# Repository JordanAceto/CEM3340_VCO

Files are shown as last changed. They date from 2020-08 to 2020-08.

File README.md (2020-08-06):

# CEM3340 based VCO PCB

## Features:
- Sine, Triangle, Sawtooth, and variable Pulse waves simultaneously available.
- All waveforms +/- 5vpp.
- Three 1 volt/octave inputs, linear FM, sync (choose hard or soft), and PWM modulation inputs.
- Onboard voltage regulators and reference voltage generators for stable tuning.
- Input voltage can be either +/- 12 volts DC, or +/- 15 volts DC.
- Designed to either plug into a separate carrier pcb with pots and jacks, or mount to a bracket and wire by hand. 

## A note about the pulse waveform:
 This design does not use the built in CEM3340 pulse generator. Instead, an typical opamp circuit is used for the Pulse wave output. This is to avoid the influence of PWM on the frequency of the oscillator, which has been reported to be a problem, especially with the AS3340 versions of the chip. The built in pulse generator is disabled by tying the output to ground through a resistor, and hardwiring a negative voltage into pin 5 which permanently sets the pulse width to zero percent.

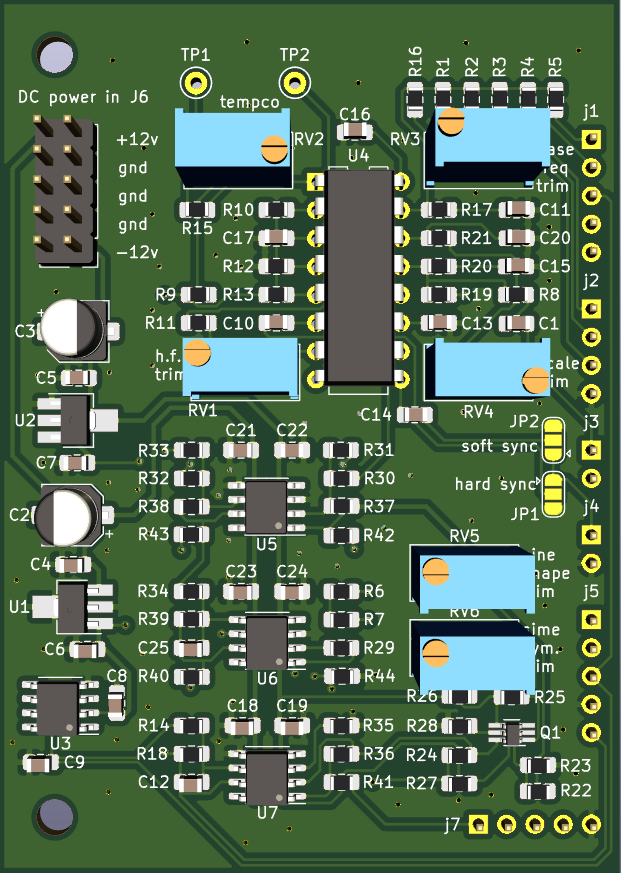
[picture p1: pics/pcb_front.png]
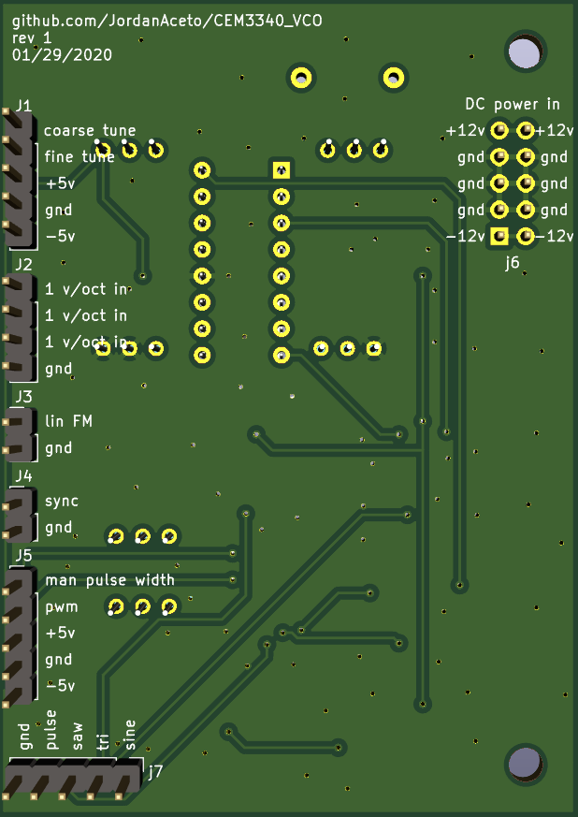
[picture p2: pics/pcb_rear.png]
   

## Status of the project:

Revision | breadboarded | schematic | pcb layout | built and tested | documentation
---------|--------------|-----------|------------|------------------|---------------
1        | &#9745;      | &#9745;   | &#9745;    | &#9745;          | &#9745; 

## Informal evaluation:

I've built three of these, and they work well and are fairly easy to build. The dual NPN in the sine shaper is a little small, but after doing a few of them I can solder them reliably without any grief.

Calibration is pretty straightforward and they tune up nicely and don't drift badly with changes in temperature. I have not done any rigorous testing, just by-ear, but I'm pretty picky about out of tune VCOs and these seem good to me so far.

Overall quite happy with this VCO.

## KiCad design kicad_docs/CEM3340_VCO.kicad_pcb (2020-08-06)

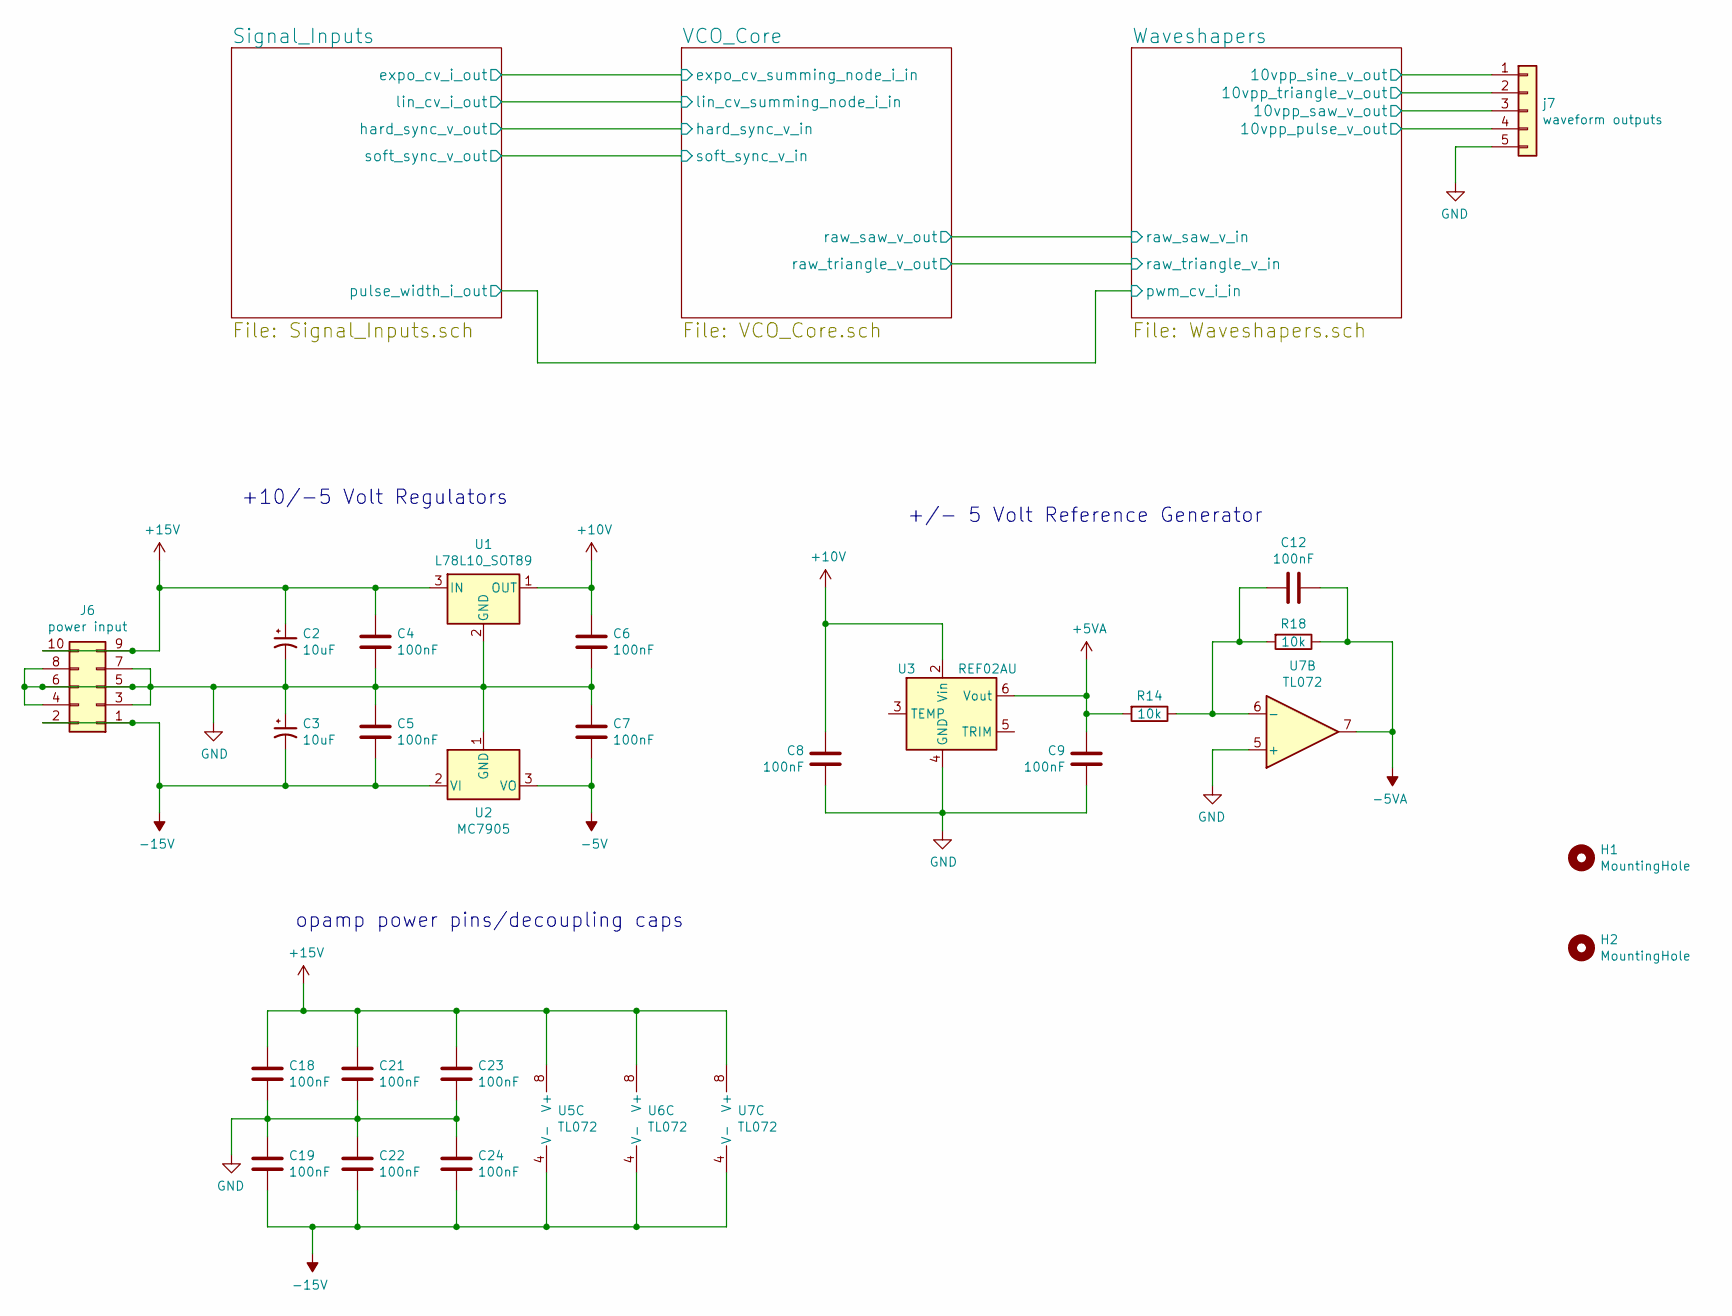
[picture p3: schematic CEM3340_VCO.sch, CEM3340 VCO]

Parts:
C2, C3: 10uF; CP_Elec_5x5.4
C4, C5, C6, C7, C8, C9, C12, C18, C19, C21, C22, C23, C24: 100nF; C_0805_2012Metric_Pad1.15x1.40mm_HandSolder
H1, H2: MountingHole; MountingHole_3.2mm_M3
J6: power input; PinHeader_2x05_P2.54mm_Vertical
R14, R18: 10k; R_0805_2012Metric_Pad1.15x1.40mm_HandSolder
U1: L78L10_SOT89; SOT-89-3_Handsoldering
U2: MC7905; SOT-89-3_Handsoldering
U3: REF02AU; SOIC-8_3.9x4.9mm_P1.27mm
U5, U6, U7: TL072; SOIC-8_3.9x4.9mm_P1.27mm
j7: waveform outputs; PinHeader_1x05_P2.54mm_Vertical

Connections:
+5VA: C9.2, R14.2, U3.6 (Vout); also elsewhere on the board
+10V: C6.2, C8.2, U1.1 (OUT), U3.2 (Vin); also elsewhere on the board
+15V: C2.1, C4.1, C18.1, C21.1, C23.1, J6.9, J6.10, U1.3 (IN), U5.8 (V+), U6.8 (V+), U7.8 (V+); also elsewhere on the board
-5V: C7.1, U2.3 (VO); also elsewhere on the board
-5VA: C12.1, R18.1, U7.7; also elsewhere on the board
-15V: C3.2, C5.2, C19.2, C22.2, C24.2, J6.1, J6.2, U2.2 (VI), U5.4 (V-), U6.4 (V-), U7.4 (V-); also elsewhere on the board
/Waveshapers/10vpp_pulse_v_out: j7.4; also elsewhere on the board
/Waveshapers/10vpp_saw_v_out: j7.3; also elsewhere on the board
/Waveshapers/10vpp_sine_v_out: j7.1; also elsewhere on the board
/Waveshapers/10vpp_triangle_v_out: j7.2; also elsewhere on the board
GND: C2.2, C3.1, C4.2, C5.1, C6.1, C7.2, C8.1, C9.1, C18.2, C19.1, C21.2, C22.1, C23.2, C24.1, J6.3, J6.4, J6.5, J6.6, J6.7, J6.8, U1.2 (GND), U2.1 (GND), U3.4 (GND), U7.5 (+), j7.5; also elsewhere on the board
unnamed: C12.2, R14.1, R18.2, U7.6 (-)

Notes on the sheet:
+/- 5 Volt Reference Generator
+10/-5 Volt Regulators
opamp power pins/decoupling caps

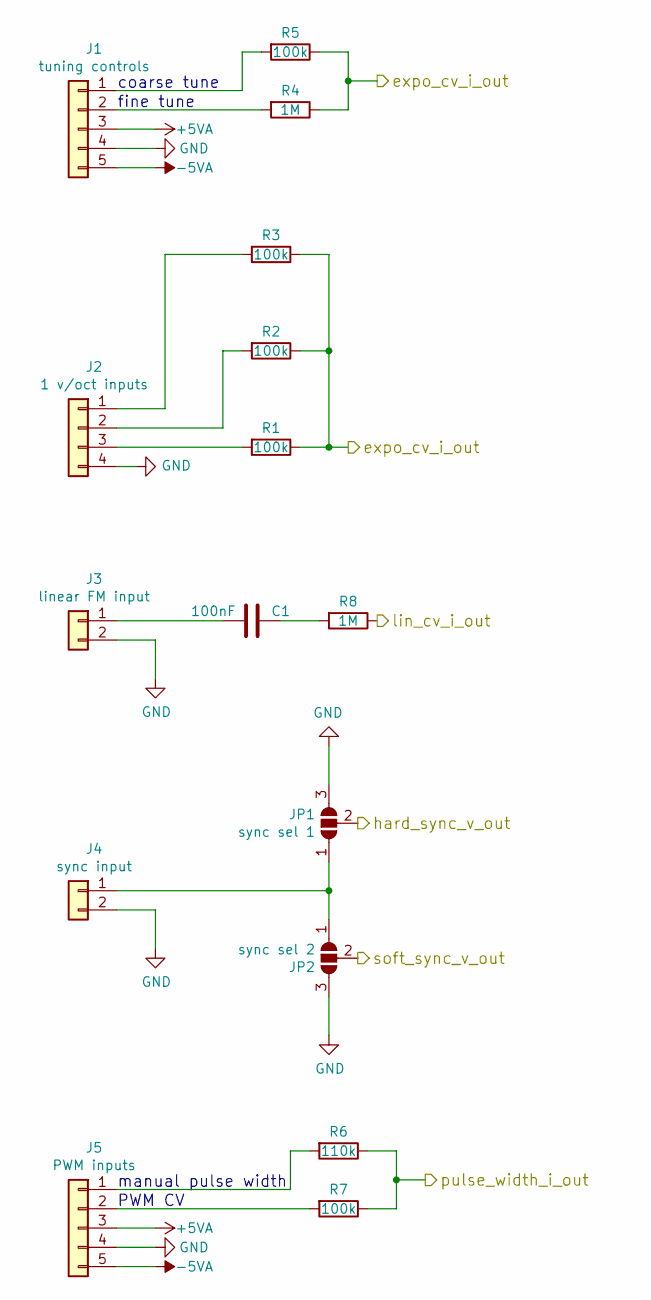
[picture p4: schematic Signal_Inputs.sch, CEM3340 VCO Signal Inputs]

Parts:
C1: 100nF; C_0805_2012Metric_Pad1.15x1.40mm_HandSolder
J1: tuning controls; PinHeader_1x05_P2.54mm_Vertical
J2: 1 v/oct inputs; PinHeader_1x04_P2.54mm_Vertical
J3: linear FM input; PinHeader_1x02_P2.54mm_Vertical
J4: sync input; PinHeader_1x02_P2.54mm_Vertical
J5: PWM inputs; PinHeader_1x05_P2.54mm_Vertical
JP1: sync sel 1; SolderJumper-3_P1.3mm_Open_RoundedPad1.0x1.5mm
JP2: sync sel 2; SolderJumper-3_P1.3mm_Open_RoundedPad1.0x1.5mm
R1, R2, R3, R5, R7: 100k; R_0805_2012Metric_Pad1.15x1.40mm_HandSolder
R4, R8: 1M; R_0805_2012Metric_Pad1.15x1.40mm_HandSolder
R6: 110k; R_0805_2012Metric_Pad1.15x1.40mm_HandSolder

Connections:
+5VA: J1.3, J5.3; also elsewhere on the board
-5VA: J1.5, J5.5; also elsewhere on the board
/Signal_Inputs/expo_cv_i_out: R1.1, R2.1, R3.1, R4.1, R5.1; also elsewhere on the board
/Signal_Inputs/lin_cv_i_out: R8.1; also elsewhere on the board
/Signal_Inputs/pulse_width_i_out: R6.1, R7.1
/VCO_Core/hard_sync_v_in: JP1.2 (C); also elsewhere on the board
/VCO_Core/soft_sync_v_in: JP2.2 (C); also elsewhere on the board
GND: J1.4, J2.4, J3.2, J4.2, J5.4, JP1.3 (B), JP2.3 (B); also elsewhere on the board
unnamed: C1.1, R8.2
unnamed: C1.2, J3.1
unnamed: J1.1, R5.2
unnamed: J1.2, R4.2
unnamed: J2.1, R3.2
unnamed: J2.2, R2.2
unnamed: J2.3, R1.2
unnamed: J4.1, JP1.1 (A), JP2.1 (A)
unnamed: J5.1, R6.2
unnamed: J5.2, R7.2

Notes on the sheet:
manual pulse width
PWM CV
fine tune
coarse tune

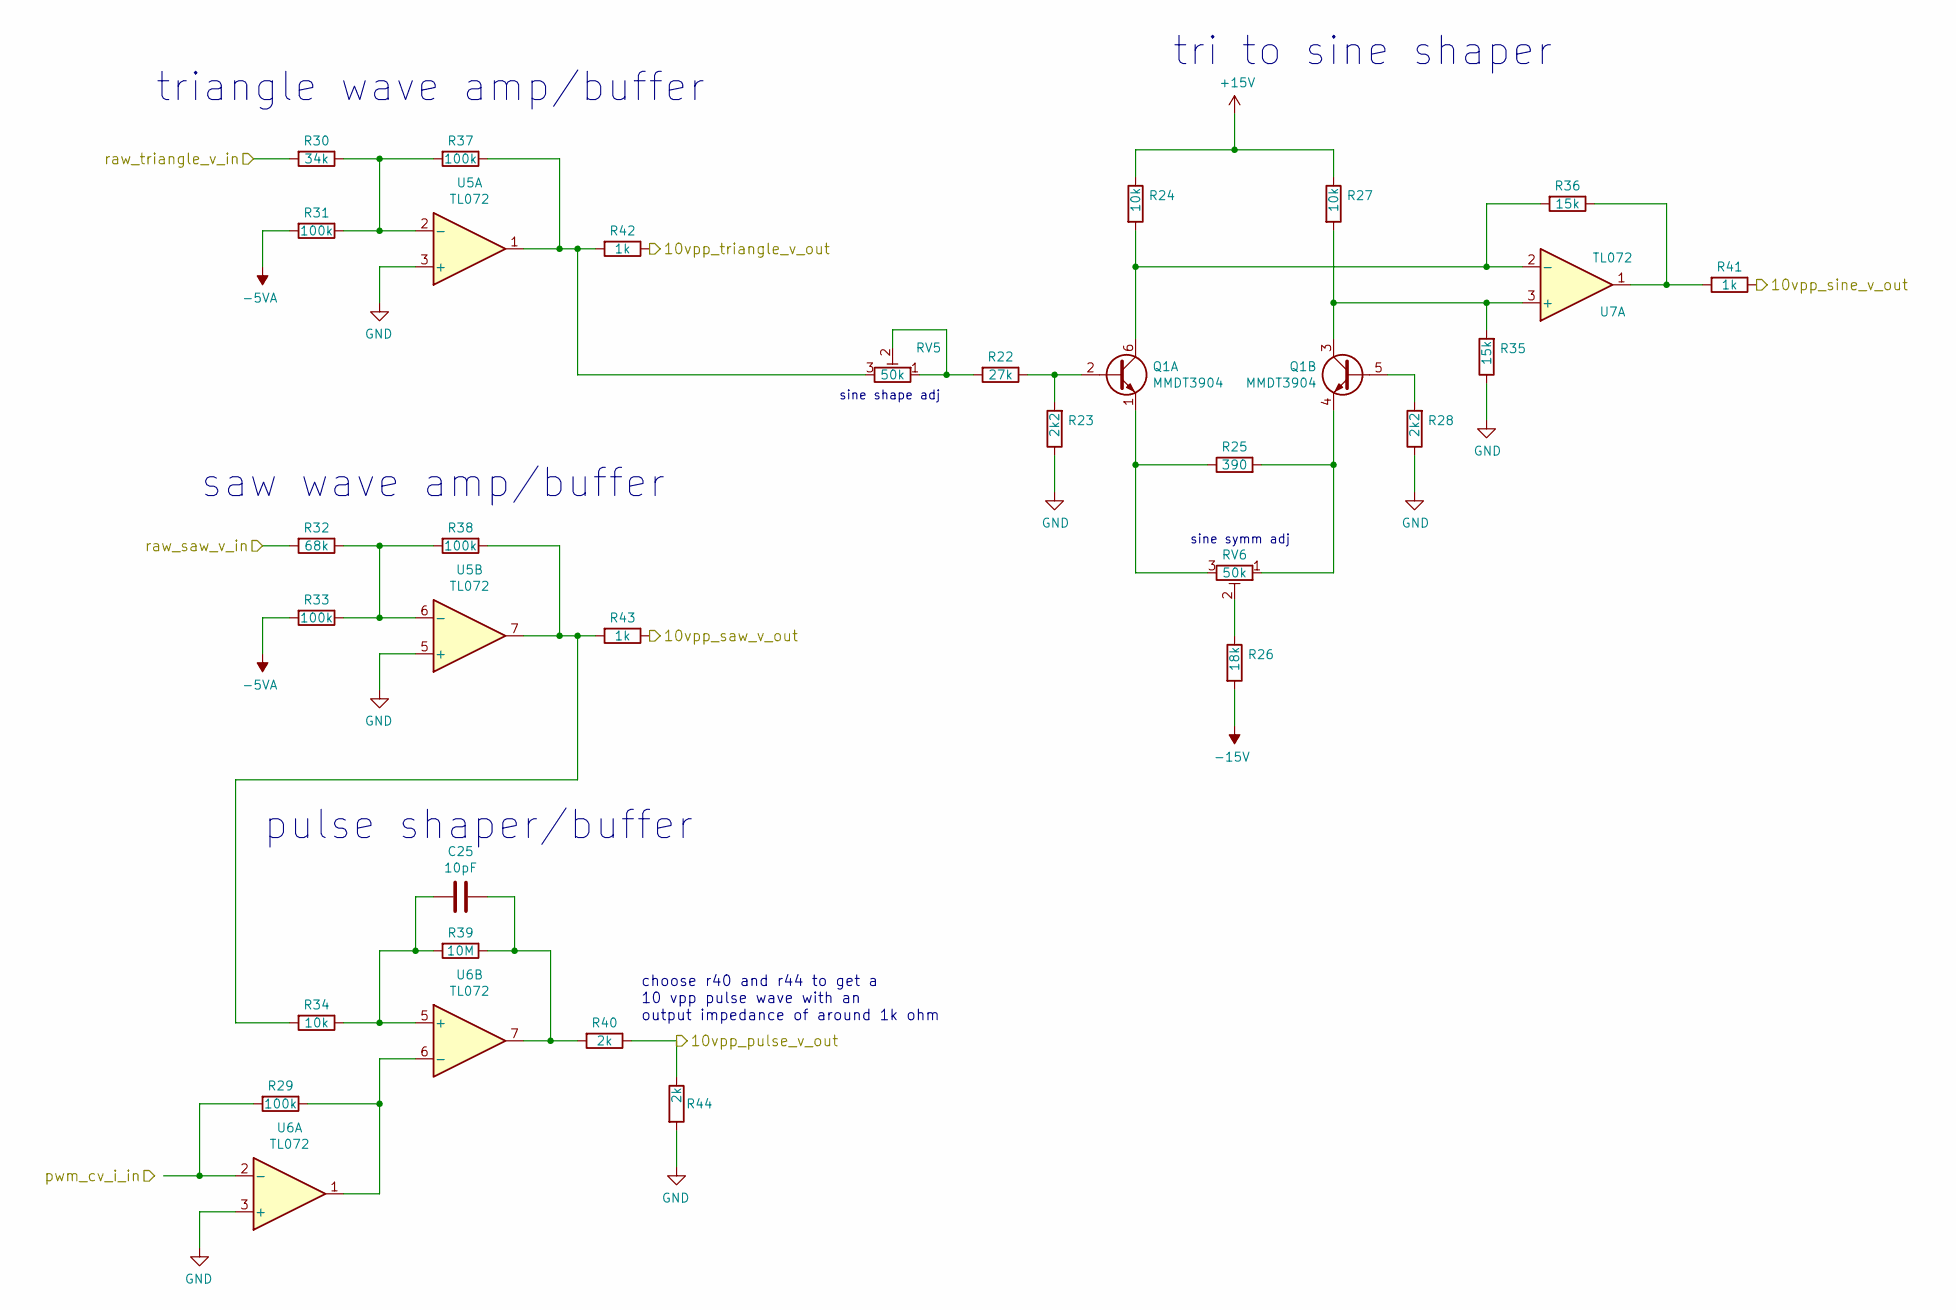
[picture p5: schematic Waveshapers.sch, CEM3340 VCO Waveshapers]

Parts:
C25: 10pF; C_0805_2012Metric_Pad1.15x1.40mm_HandSolder
Q1: MMDT3904; SOT-363_SC-70-6_Handsoldering
R22: 27k; R_0805_2012Metric_Pad1.15x1.40mm_HandSolder
R23, R28: 2k2; R_0805_2012Metric_Pad1.15x1.40mm_HandSolder
R24, R27, R34: 10k; R_0805_2012Metric_Pad1.15x1.40mm_HandSolder
R25: 390; R_0805_2012Metric_Pad1.15x1.40mm_HandSolder
R26: 18k; R_0805_2012Metric_Pad1.15x1.40mm_HandSolder
R29, R31, R33, R37, R38: 100k; R_0805_2012Metric_Pad1.15x1.40mm_HandSolder
R30: 34k; R_0805_2012Metric_Pad1.15x1.40mm_HandSolder
R32: 68k; R_0805_2012Metric_Pad1.15x1.40mm_HandSolder
R35, R36: 15k; R_0805_2012Metric_Pad1.15x1.40mm_HandSolder
R39: 10M; R_0805_2012Metric_Pad1.15x1.40mm_HandSolder
R40, R44: 2k; R_0805_2012Metric_Pad1.15x1.40mm_HandSolder
R41, R42, R43: 1k; R_0805_2012Metric_Pad1.15x1.40mm_HandSolder
RV5, RV6: 50k; Potentiometer_Bourns_3296W_Vertical
U5, U6, U7: TL072; SOIC-8_3.9x4.9mm_P1.27mm

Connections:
+15V: R24.1, R27.1; also elsewhere on the board
-5VA: R31.2, R33.2; also elsewhere on the board
-15V: R26.2; also elsewhere on the board
/Waveshapers/10vpp_pulse_v_out: R40.1, R44.1; also elsewhere on the board
/Waveshapers/10vpp_saw_v_out: R43.1; also elsewhere on the board
/Waveshapers/10vpp_sine_v_out: R41.1; also elsewhere on the board
/Waveshapers/10vpp_triangle_v_out: R42.1; also elsewhere on the board
/Waveshapers/raw_saw_v_in: R32.2; also elsewhere on the board
/Waveshapers/raw_triangle_v_in: R30.2; also elsewhere on the board
GND: R23.1, R28.1, R35.1, R44.2, U5.3 (+), U5.5 (+), U6.3 (+); also elsewhere on the board
unnamed: C25.1, R39.1, R40.2, U6.7
unnamed: C25.2, R34.1, R39.2, U6.5 (+)
unnamed: Q1.1 (E1), R25.1, RV6.3
unnamed: Q1.2 (B1), R22.1, R23.2
unnamed: Q1.3 (C2), R27.2, R35.2, U7.3 (+)
unnamed: Q1.4 (E2), R25.2, RV6.1
unnamed: Q1.5 (B2), R28.2
unnamed: Q1.6 (C1), R24.2, R36.2, U7.2 (-)
unnamed: R22.2, RV5.1, RV5.2
unnamed: R26.1, RV6.2
unnamed: R29.1, U6.1, U6.6 (-)
unnamed: R29.2, U6.2 (-)
unnamed: R30.1, R31.1, R37.2, U5.2 (-)
unnamed: R32.1, R33.1, R38.2, U5.6 (-)
unnamed: R34.2, R38.1, R43.2, U5.7
unnamed: R36.1, R41.2, U7.1
unnamed: R37.1, R42.2, RV5.3, U5.1

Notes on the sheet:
sine shape adj
sine symm adj
tri to sine shaper
triangle wave amp/buffer
saw wave amp/buffer
pulse shaper/buffer
choose r40 and r44 to get a 10 vpp pulse wave with an output impedance of around 1k ohm

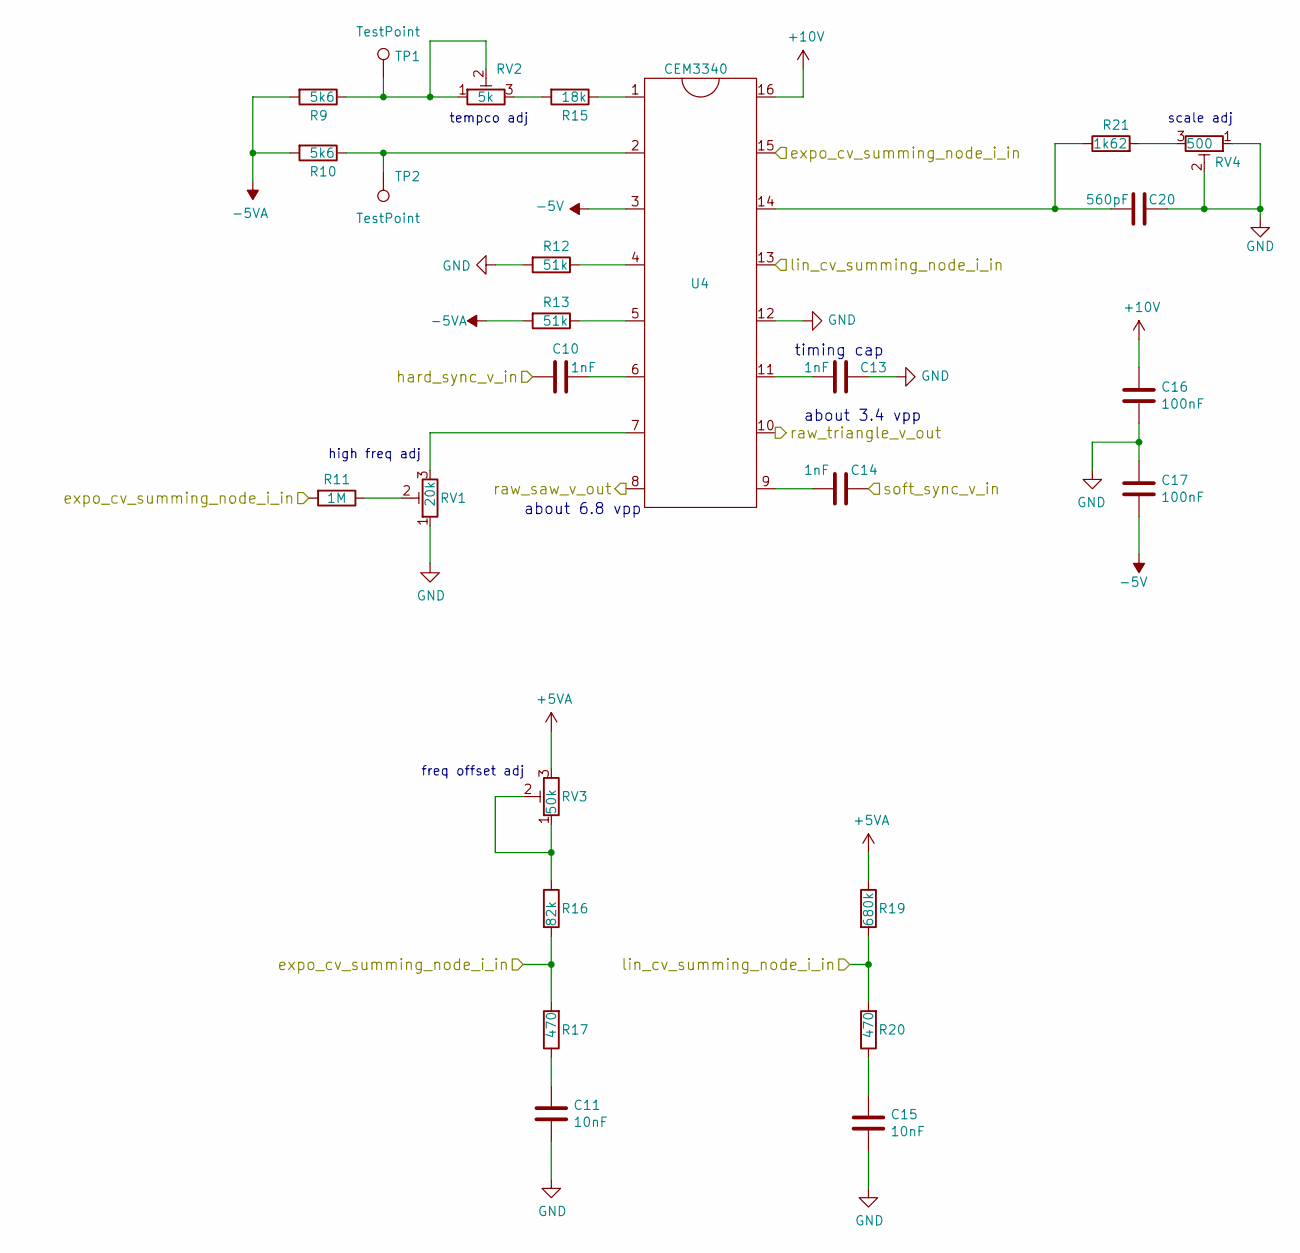
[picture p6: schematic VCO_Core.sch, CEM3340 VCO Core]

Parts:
C10, C13, C14: 1nF; C_0805_2012Metric_Pad1.15x1.40mm_HandSolder
C11, C15: 10nF; C_0805_2012Metric_Pad1.15x1.40mm_HandSolder
C16, C17: 100nF; C_0805_2012Metric_Pad1.15x1.40mm_HandSolder
C20: 560pF; C_0805_2012Metric_Pad1.15x1.40mm_HandSolder
R9, R10: 5k6; R_0805_2012Metric_Pad1.15x1.40mm_HandSolder
R11: 1M; R_0805_2012Metric_Pad1.15x1.40mm_HandSolder
R12, R13: 51k; R_0805_2012Metric_Pad1.15x1.40mm_HandSolder
R15: 18k; R_0805_2012Metric_Pad1.15x1.40mm_HandSolder
R16: 82k; R_0805_2012Metric_Pad1.15x1.40mm_HandSolder
R17, R20: 470; R_0805_2012Metric_Pad1.15x1.40mm_HandSolder
R19: 680k; R_0805_2012Metric_Pad1.15x1.40mm_HandSolder
R21: 1k62; R_0805_2012Metric_Pad1.15x1.40mm_HandSolder
RV1: 20k; Potentiometer_Bourns_3296W_Vertical
RV2: 5k; Potentiometer_Bourns_3296W_Vertical
RV3: 50k; Potentiometer_Bourns_3296W_Vertical
RV4: 500; Potentiometer_Bourns_3296W_Vertical
TP1, TP2: TestPoint; TestPoint_Keystone_5000-5004_Miniature
U4: CEM3340; DIP-16_W7.62mm

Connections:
+5VA: R19.1, RV3.3; also elsewhere on the board
+10V: C16.1, U4.16; also elsewhere on the board
-5V: C17.2, U4.3; also elsewhere on the board
-5VA: R9.2, R10.2, R13.2; also elsewhere on the board
/Signal_Inputs/expo_cv_i_out: R11.2, R16.2, R17.2, U4.15; also elsewhere on the board
/Signal_Inputs/lin_cv_i_out: R19.2, R20.2, U4.13; also elsewhere on the board
/VCO_Core/hard_sync_v_in: C10.2; also elsewhere on the board
/VCO_Core/soft_sync_v_in: C14.1; also elsewhere on the board
/Waveshapers/raw_saw_v_in: U4.8; also elsewhere on the board
/Waveshapers/raw_triangle_v_in: U4.10; also elsewhere on the board
GND: C11.2, C13.1, C15.2, C16.2, C17.1, C20.2, R12.2, RV1.1, RV4.1, RV4.2, U4.12; also elsewhere on the board
unnamed: C10.1, U4.6
unnamed: C11.1, R17.1
unnamed: C13.2, U4.11
unnamed: C14.2, U4.9
unnamed: C15.1, R20.1
unnamed: C20.1, R21.1, U4.14
unnamed: R9.1, RV2.1, RV2.2, TP1.1
unnamed: R10.1, TP2.1, U4.2
unnamed: R11.1, RV1.2
unnamed: R12.1, U4.4
unnamed: R13.1, U4.5
unnamed: R15.1, U4.1
unnamed: R15.2, RV2.3
unnamed: R16.1, RV3.1, RV3.2
unnamed: R21.2, RV4.3
unnamed: RV1.3, U4.7

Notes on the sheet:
tempco adj
scale adj
freq offset adj
high freq adj
timing cap
about 3.4 vpp
about 6.8 vpp

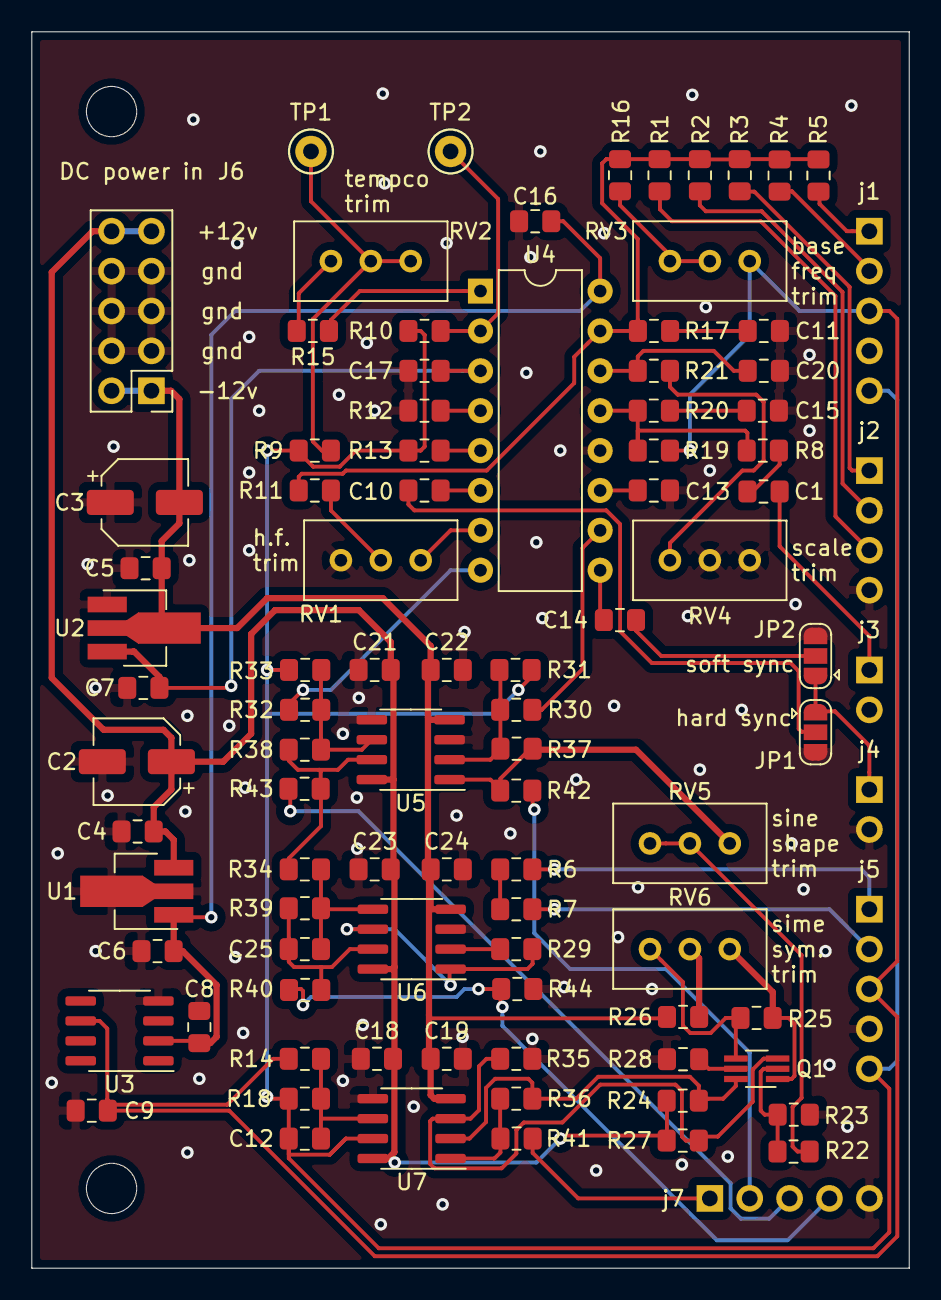
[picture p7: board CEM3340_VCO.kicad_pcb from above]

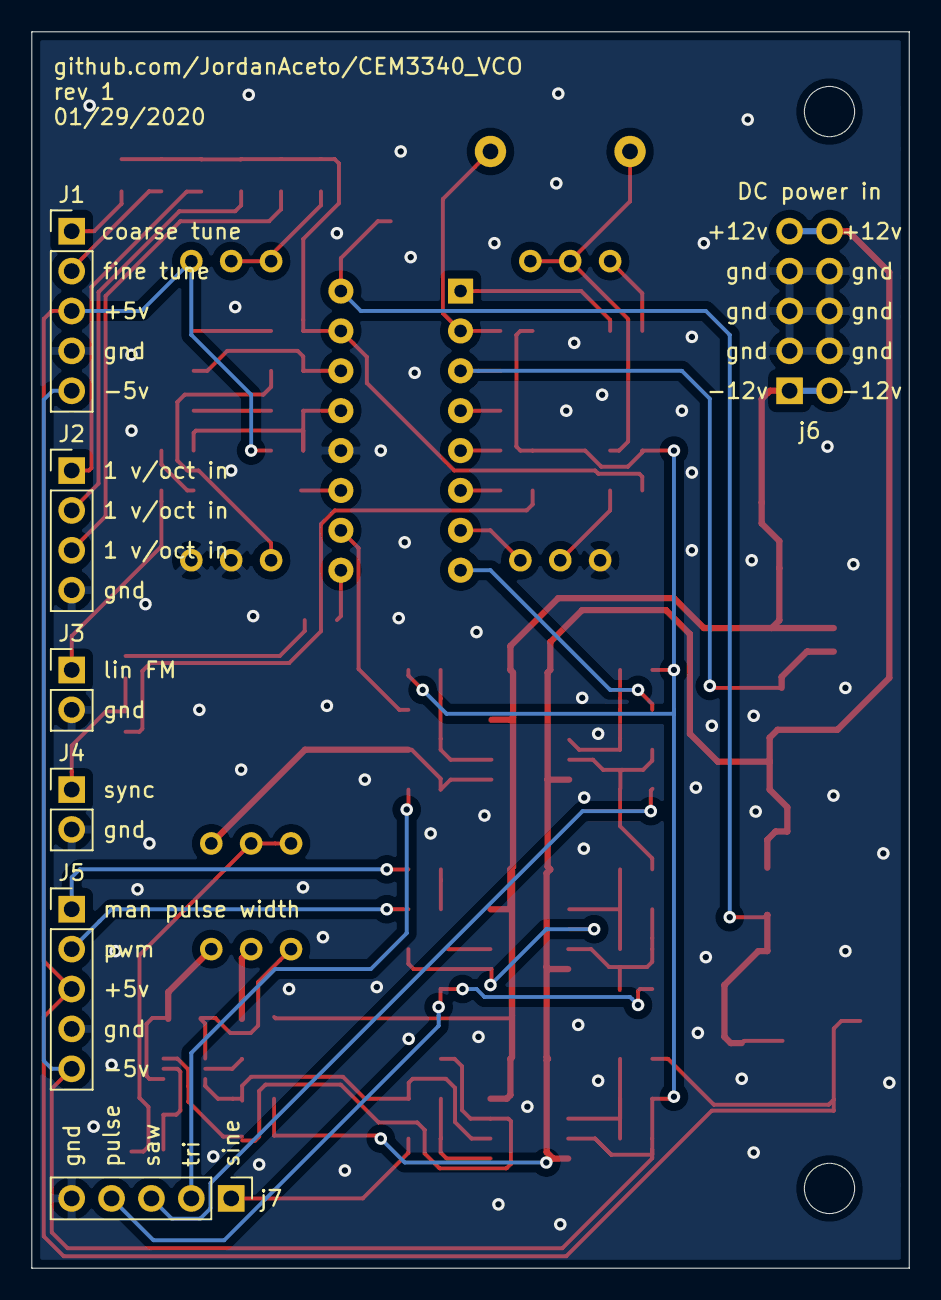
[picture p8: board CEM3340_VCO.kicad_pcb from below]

Board: 2 copper layers, 55.9 x 78.7 mm, 96 parts (6 on the bottom side), 62 nets.

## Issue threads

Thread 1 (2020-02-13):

Transistor pair is too small.

JordanAceto, 2020-02-13:
The MMDT3904 matched transistor pair Q1 package is too small to easily/reliably hand solder. This part should be replaced by either a larger NPN pair, or 2 discrete NPN transistors in reasonably sized packages.

A cheap matched pair that comes in a (fairly) easily hand soldered package can be found here: https://www.mouser.com/ProductDetail/771-BCM847DS115

JordanAceto, 2020-08-06:
It's really not too bad after doing a few of them. If a new pcb rev happens then sure, put in a bigger package, but don't do it just for this.

Closed 2020-08-06.

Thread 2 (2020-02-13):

Sine adjustment should not rely on the raw power input voltage

JordanAceto, 2020-02-13:
The sine wave shaper transistor pair Q1 is across the raw +/- DC power supply input rails. For sine calibration that does not depend on the input voltage, this should be changed so that it is across the derived +10/-5 volt sub-rails. Some adjustment of component values may be needed.

JordanAceto, 2020-08-06:
This is not really an issue in practice. This is a set-and-forget trim, and it isn't super duper critical. Experiment with this if you want, but don't spend time worrying about it.

Closed 2020-08-06.

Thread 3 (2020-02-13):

Some resistor values are unknown

JordanAceto, 2020-02-13:
Values for resistors R4, R5, R31, and R32. Determine appropriate values for these resistors and update the schematic and BOM.

Closed 2020-02-15.

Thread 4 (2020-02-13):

Pulse wave output voltage should not rely on the input voltage

JordanAceto, 2020-02-13:
The pulse wave output level is set by a resistive divider. Replace this resistive divider with a zener diode clamp or other method of establishing a +/-5 volt peak to peak pulse wave that is independent of the input power supply.

JordanAceto, 2020-08-06:
This is not really a problem unless you're going to be swapping the pcb between 15 volt and 12 volt systems, which seems pretty unlikely.

This could be incorporated into a new pcb rev if desired, but it isn't worth spending time extra on.

Closed 2020-08-06.

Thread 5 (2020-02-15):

Sine level is a bit low.

JordanAceto, 2020-02-15:
The sine level on a built pcb is around 8 vpp. Adjust resistor values in order to create a sine wave that is between 10 vpp and 11 vpp.

JordanAceto, 2020-02-19:
Resistors R35 and R36 changed to 15k, this brings the sine level up to just over 10vpp. Issue closed.

Closed 2020-02-19.

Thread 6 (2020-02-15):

There should be the option to clip the PWM signal.

JordanAceto, 2020-02-15:
PWM is a matter of personal taste. Some designs allow you to "overdrive" the PWM, so that the pulse wave completely disappears as you modulate below 0% and above 100%. Other designs clip the PWM so that the pulse wave never completely disappears.

This design in its current incarnation does not clip the PWM signal and allows for overdrive.

Add a zener network or other clipping strategy so that the pulse width is clamped between around 5% and 95%.

The builder can then choose to either install or leave off the clipping network, according to their taste.

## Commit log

2020-01-29 initial commit, schem and pcb underway, not final
    [CEM3340_VCO.kicad_pcb, CEM3340_VCO.sch]
2020-01-29 place github url on pcb silk
    [CEM3340_VCO.kicad_pcb]
2020-01-29 generate gerbers
    [CEM3340_VCO-B_Cu.gbr, CEM3340_VCO-B_Mask.gbr, CEM3340_VCO-B_SilkS.gbr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]
2020-01-29 change mounting holes to pth
    [CEM3340_VCO.kicad_pcb]
2020-01-29 regenerate BOM, better but not done
    [CEM3340_VCO_BOM.ods]
2020-01-30 extract circuit blocks into separate schem pages
    [CEM3340_VCO.kicad_pcb, CEM3340_VCO.sch, Signal_Inputs.sch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]
2020-01-30 add pdf schematic
2020-02-15 update and fill in some resistor values
    [CEM3340_VCO.sch, Signal_Inputs.sch, VCO_Core.sch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]
2020-02-15 update pdf schematic with new resistor values
2020-02-15 increase sine level to 10vpp
    [Waveshapers.sch]
2020-08-06 finalize some values, update documentation
    [CEM3340_VCO.kicad_pcb, CEM3340_VCO.sch, Waveshapers.sch]

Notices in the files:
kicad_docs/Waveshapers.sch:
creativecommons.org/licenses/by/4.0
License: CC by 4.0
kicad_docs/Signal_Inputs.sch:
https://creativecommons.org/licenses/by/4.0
